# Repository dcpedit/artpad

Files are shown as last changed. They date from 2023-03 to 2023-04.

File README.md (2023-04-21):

# ArtPad

artpad-3

Video: https://youtube.com/shorts/0jcIEa7Fye8

ArtPad is designed to be an artisian tray that also functions as a macro pad.  This repository contains two PCB designs.  `pcb` is the Choc hotswap version, and `pcb-chocmini` uses Choc Mini switches which can be built to be slightly thinner.  Both PCBs feature per-key RGB, an OLED display, and an optional rotary encoder.

## PCB Details
My original design uses Choc hotswap sockets which offers the most versatility since Choc switches come in a varity of flavors.  I later decided to design a slimmer version that uses Choc Mini switches, but limits you to only 3 types of switches (linear, tactile, and clicky) and is not hotswapable.  Below are the heights measured from the lowest point of the switch (pin) to the top of the keycap ([wrk pure](https://worklouder.cc/shop/wrk-pure/) from Work Louder).

| Choc PCB | Choc Mini PCB |
|---|---|
| 13.5mm | 11mm |

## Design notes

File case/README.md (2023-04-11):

# Stacked Acrylic Case

This case was designed for the Choc Mini PCB.

https://user-images.githubusercontent.com/800930/230827112-2fbff8e4-7619-4b2e-93d9-0d07b0fd45db.mp4

## BOM
| Part | Count | Notes |
|---|---|---|
| 3mm Acrylic | 6 | 
| 1mm EVA Foam | 1 | Optional
| M2x10mm Standoff | 4 | 
| M2x6mm Screw | 8 |

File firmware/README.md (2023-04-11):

# Vial Firmware

This firmware was compiled for the Elite-C development board.  Once flashed, you can use Vial to remap your keys:

https://get.vial.today

# Source Files

https://github.com/dcpedit/vial-qmk/tree/vial/keyboards/dcpedit/artpad

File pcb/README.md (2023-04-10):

# Choc Hotswap PCB
This PCB has not yet been tested



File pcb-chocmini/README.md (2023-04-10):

# Choc Mini PCB

chocmini-pcb

## JLCPCB File
`artpad_mini.zip`

artpad-1

## BOM
| Part | Count | Notes |
|---|---|---|
| Choc Mini Switches | 15 - 16 | 
| Choc Keycaps | 15 - 16 | [wrk pure](https://worklouder.cc/shop/wrk-pure/)
| 1N4148 SMD Diode | 16 | 
| SK6812 MINI-E RGB LED | 16 | [Link](https://www.diykeyboards.com/parts/electronics/product/sk6812-mini-e-rgb-led)
| SD1306 OLED | 1 | [Link](https://www.diykeyboards.com/parts/electronics/product/p128x32-oled-lcd-display-ssd1306-driver)
| EC11 Rotary Encoder | 1 |
| Rotary Encoder Knob | 1 |
| Mill-Max 315 low-profile headers (1x12) | 2 | [Link](https://www.littlekeyboards.com/products/ultra-low-profile-sockets?variant=39323794800707)
| Mill-Max round pins | 24 | 
| Elite-C controller | 1 |

## Instructions

The assembly is pretty straight forward.  In order to keep things low profile, you should opt for the SMD diodes since through hole diodes will add to the overall thickness.  The LEDs have one pin with a corner cut off.  Line that pin up with pad that has the triangle printed next to it.

For my build, I used low-profile headers for the Elite-C, but I didn't bother with headers for the OLED since it would be too difficult to get the height exactly right.  I just put a piece of electrical tape under the OLED and placed it right on top of the Elite-C so that both were touching.  Then soldered it in while holding it in place.

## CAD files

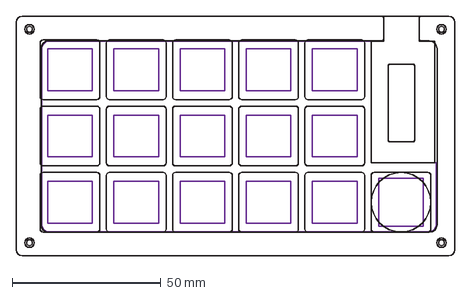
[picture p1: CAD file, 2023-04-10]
case/case.dxf
147.2 x 80.5 mm

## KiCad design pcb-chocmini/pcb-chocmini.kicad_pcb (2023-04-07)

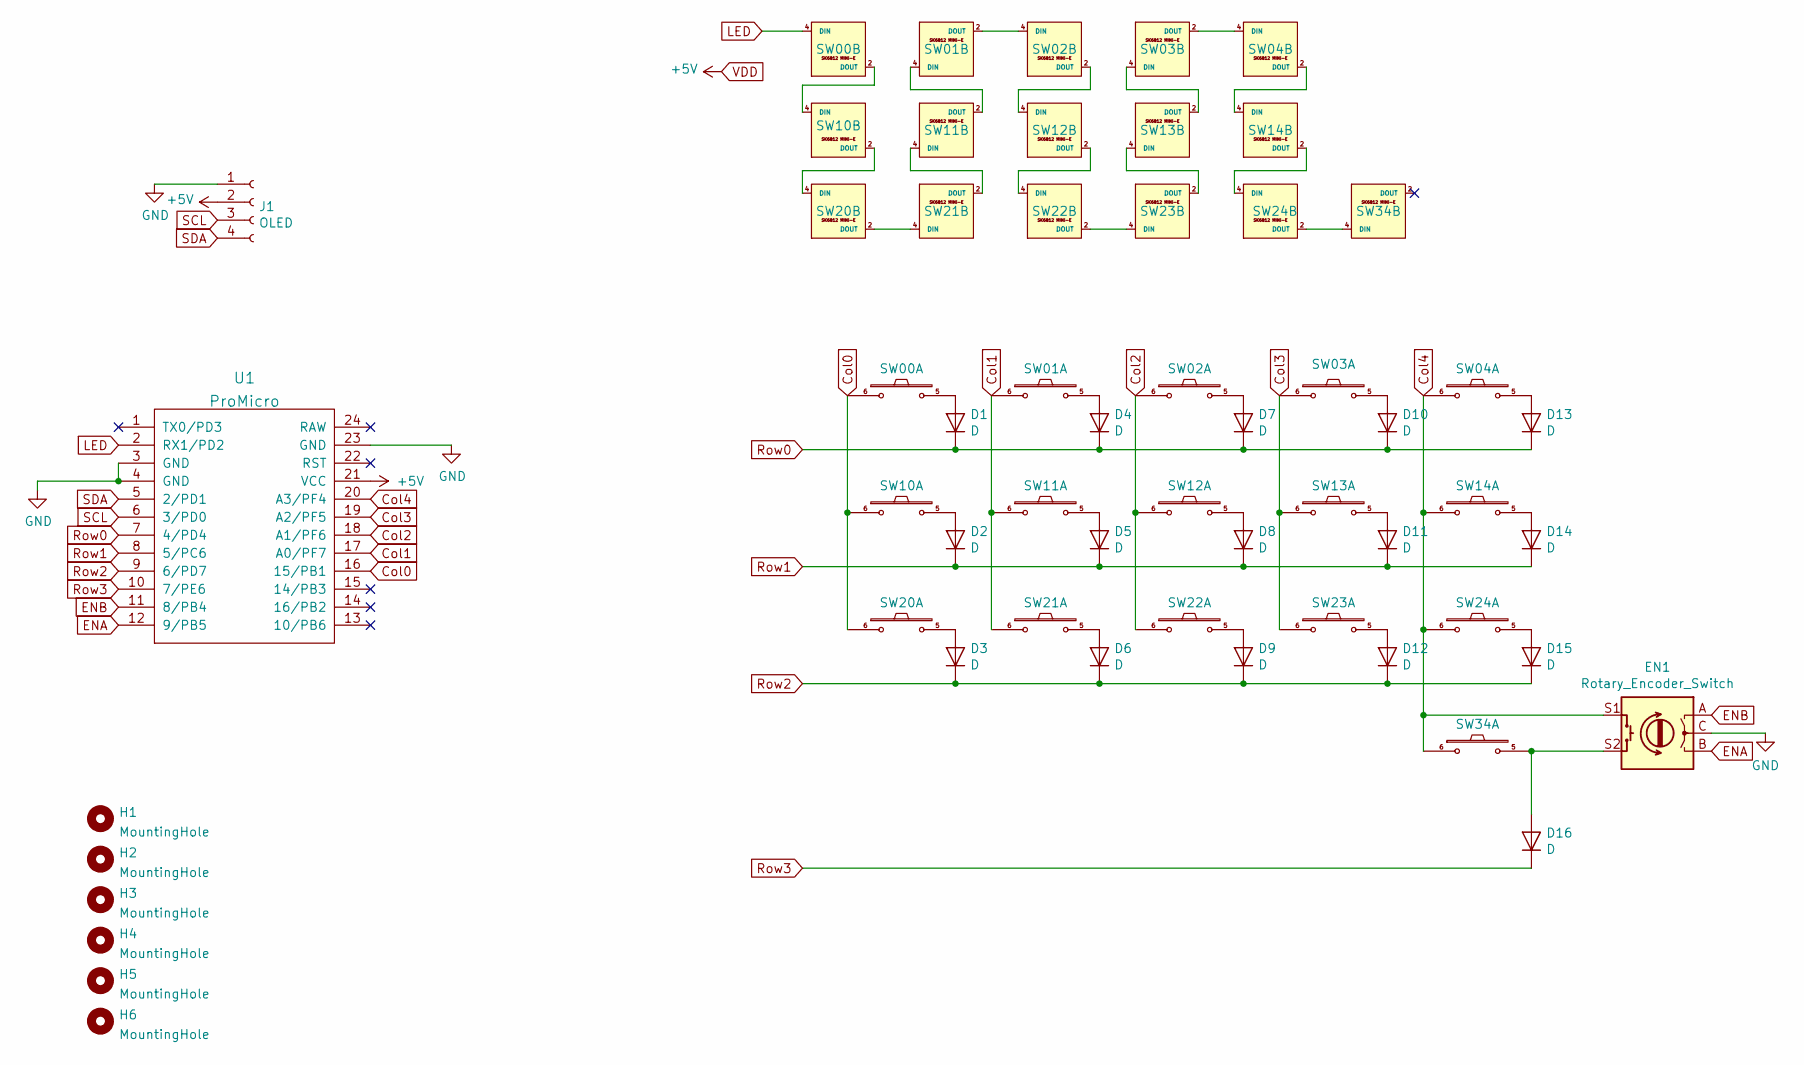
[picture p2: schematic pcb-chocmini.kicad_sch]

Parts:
D1, D2, D3, D4, D5, D6, D7, D8, D9, D10, D11, D12, D13, D14, D15, D16: D; crkbd-diode
EN1: Rotary_Encoder_Switch; RotaryEncoder_Alps_EC11E-Switch_Vertical_H20mm
H1, H2, H3, H4, H5, H6: MountingHole
J1: OLED; SSD1306_OLED
SW00, SW01, SW02, SW03, SW04, SW10, SW11, SW12, SW13, SW14, SW20, SW21, SW22, SW23, SW24, SW34: SW_PUSH_LED; Choc_Hotswap_SK6812MiniE
U1: ProMicro

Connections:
Col0: SW00.6, SW10.6, SW20.6, U1.16 (15/PB1)
Col1: SW01.6, SW11.6, SW21.6, U1.17 (A0/PF7)
Col2: SW02.6, SW12.6, SW22.6, U1.18 (A1/PF6)
Col3: SW03.6, SW13.6, SW23.6, U1.19 (A2/PF5)
Col4: EN1.S1, SW04.6, SW14.6, SW24.6, SW34.6, U1.20 (A3/PF4)
ENA: EN1.B, U1.12 (9/PB5)
ENB: EN1.A, U1.11 (8/PB4)
GND: EN1.C, J1.1, SW00.3 (GND), SW01.3 (GND), SW02.3 (GND), SW03.3 (GND), SW04.3 (GND), SW10.3 (GND), SW11.3 (GND), SW12.3 (GND), SW13.3 (GND), SW14.3 (GND), SW20.3 (GND), SW21.3 (GND), SW22.3 (GND), SW23.3 (GND), SW24.3 (GND), SW34.3 (GND), U1.3 (GND), U1.4 (GND), U1.23 (GND)
LED: SW00.4 (DIN), U1.2 (RX1/PD2)
unnamed: D1.2 (A), SW00.5
unnamed: D2.2 (A), SW10.5
unnamed: D3.2 (A), SW20.5
unnamed: D4.2 (A), SW01.5
unnamed: D5.2 (A), SW11.5
unnamed: D6.2 (A), SW21.5
unnamed: D7.2 (A), SW02.5
unnamed: D8.2 (A), SW12.5
unnamed: D9.2 (A), SW22.5
unnamed: D10.2 (A), SW03.5
unnamed: D11.2 (A), SW13.5
unnamed: D12.2 (A), SW23.5
unnamed: D13.2 (A), SW04.5
unnamed: D14.2 (A), SW14.5
unnamed: D15.2 (A), SW24.5
unnamed: D16.2 (A), EN1.S2, SW34.5
unnamed: SW00.2 (DOUT), SW10.4 (DIN)
unnamed: SW01.2 (DOUT), SW02.4 (DIN)
unnamed: SW01.4 (DIN), SW11.2 (DOUT)
unnamed: SW02.2 (DOUT), SW12.4 (DIN)
unnamed: SW03.2 (DOUT), SW04.4 (DIN)
unnamed: SW03.4 (DIN), SW13.2 (DOUT)
unnamed: SW04.2 (DOUT), SW14.4 (DIN)
unnamed: SW10.2 (DOUT), SW20.4 (DIN)
unnamed: SW11.4 (DIN), SW21.2 (DOUT)
unnamed: SW12.2 (DOUT), SW22.4 (DIN)
unnamed: SW13.4 (DIN), SW23.2 (DOUT)
unnamed: SW14.2 (DOUT), SW24.4 (DIN)
unnamed: SW20.2 (DOUT), SW21.4 (DIN)
unnamed: SW22.2 (DOUT), SW23.4 (DIN)
unnamed: SW24.2 (DOUT), SW34.4 (DIN)
Row0: D1.1 (K), D4.1 (K), D7.1 (K), D10.1 (K), D13.1 (K), U1.7 (4/PD4)
Row1: D2.1 (K), D5.1 (K), D8.1 (K), D11.1 (K), D14.1 (K), U1.8 (5/PC6)
Row2: D3.1 (K), D6.1 (K), D9.1 (K), D12.1 (K), D15.1 (K), U1.9 (6/PD7)
Row3: D16.1 (K), U1.10 (7/PE6)
SCL: J1.3, U1.6 (3/PD0)
SDA: J1.4, U1.5 (2/PD1)
VDD: J1.2, SW00.1 (VDD), SW01.1 (VDD), SW02.1 (VDD), SW03.1 (VDD), SW04.1 (VDD), SW10.1 (VDD), SW11.1 (VDD), SW12.1 (VDD), SW13.1 (VDD), SW14.1 (VDD), SW20.1 (VDD), SW21.1 (VDD), SW22.1 (VDD), SW23.1 (VDD), SW24.1 (VDD), SW34.1 (VDD), U1.21 (VCC)

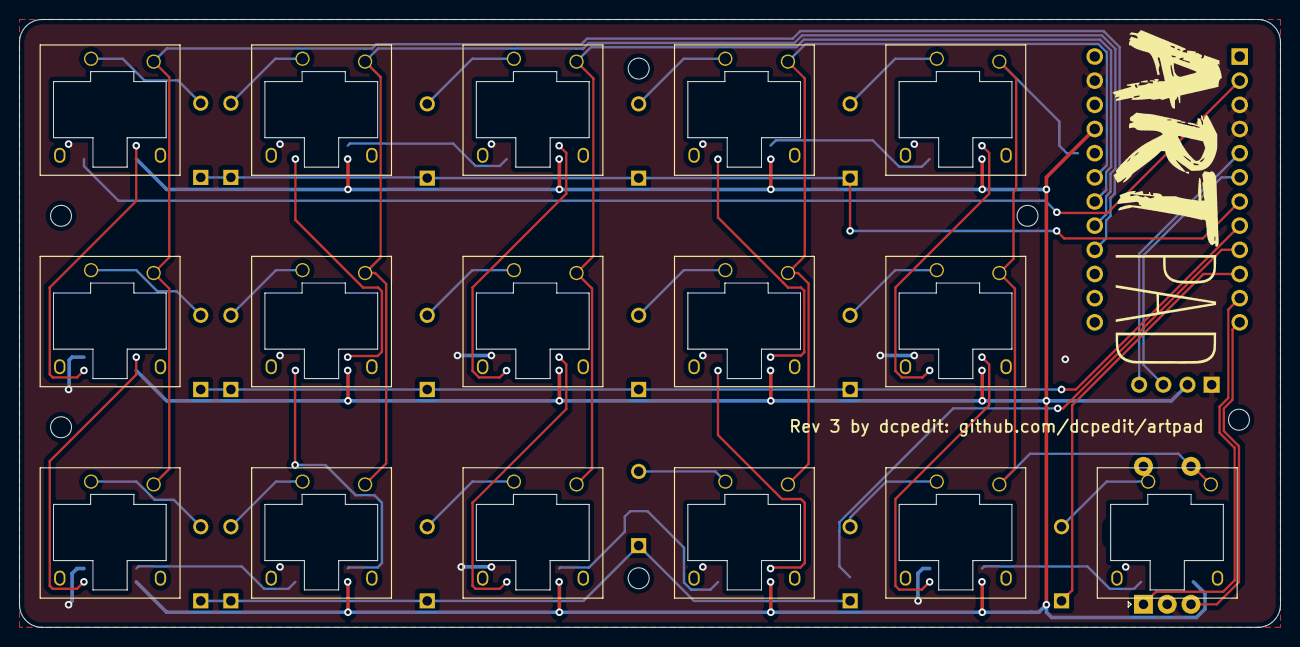
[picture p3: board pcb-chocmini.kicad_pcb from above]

Board: 2 copper layers, 132.6 x 63.9 mm, 41 parts (1 on the bottom side), 47 nets.
